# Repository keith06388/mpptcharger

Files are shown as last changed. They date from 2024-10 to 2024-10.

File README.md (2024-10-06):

# Backpacking MPPT Solar Charger
Solar charger designed to charge lithium ion cells directly, bypassing USB charging circuit.  


## Features

Advantages of this design:
* Very high efficiecy buck converter
* Psuedo MPPT tracking using BQ24650 chip
* Intergrated power meter and battery charge status
* Passthrough charging to charge device and battery simultaneously
* Integrated battery attachment for simple attachment to pack while hiking
* Adjustable to different panel voltages
* Avoid 2 stage voltage drop to cells for higher total efficiency (solar -> battery vs solar -> USB -> battery)
* Magnetic battery contacts designed to avoid reverse polarity connection
* Compatability with both Nitecore NL2150RX and Vapcell P2150A

## PCB
* Designed with easyeda software
* PCBA assembled by JLCPCB
* Primary components:
*   BQ24650 - mppt solar battery charging chip
*   ATTINY1616 - arduino compatable microcontroller
*   INA181A2 - current sense amplifier for power calculation

## 3D Printed Parts
* Housing (printed with ASA)
* Positve and negative battery contacts (printed with PETG)
*   Printing of the positive contact was paused to allow installation of the magnet into the housing before lip printed

## Purchased Parts
* Magents from K&J (D42AH and D62SH)
*   High temperature magnets to allow soldering without demagnetization
* Sn42Bi58 solder for attaching wire to magnets at low temperature
* 20AWG silicone flexible wire (red and black)
* 0.49" SSD1306 OLED
* 28.2mmx33mmx2.4mm 50D silicone o-ring
* 1.5mm nano tape (adds friction to prevent cell slipping)
* Short piece of flat wire (used for programming after assembly)
* Lixada solar panel

## Assembly
Testing of the performance was completed by modifying a Lixada solar panel purchased from Amazon

Installation steps:
* Carefully remove solar to USB module from panel using a razor blade to cut adhesive under module and a soldering iron to desolder leads from panel
* Scrape any remaining adhesive off and clean with alcohol
* Solder new assembled pcb with housing and leads to panel
* Use epoxy to glue housing to panel









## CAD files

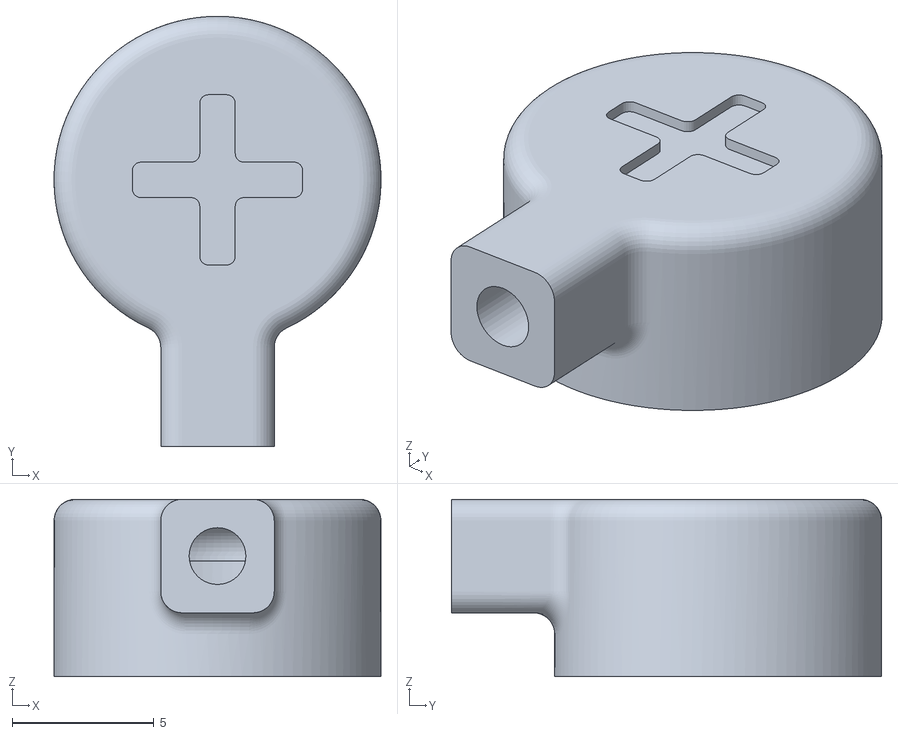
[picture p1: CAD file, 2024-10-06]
3D Printed Parts/Plus.stl
11.5 x 15.2 x 6.25

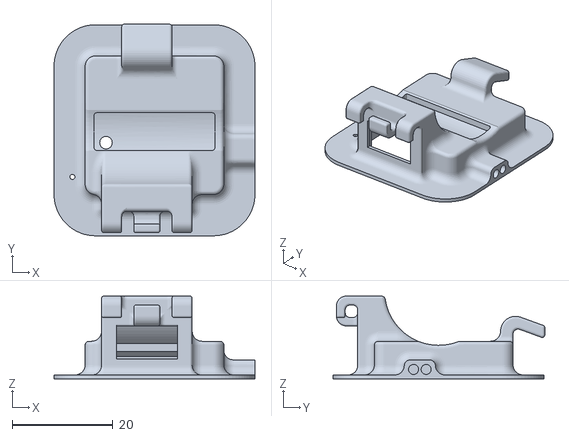
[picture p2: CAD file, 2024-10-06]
3D Printed Parts/Cover.stl
40.0 x 42.1 x 16.5

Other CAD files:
3D Printed Parts/Minus.3mf

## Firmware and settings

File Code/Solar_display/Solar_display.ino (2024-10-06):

#include <Tiny4kOLED.h>
#include "spleen.h"
#include "batt.h"

uint8_t currentCharacter;
uint8_t i = 0;
uint8_t lvl = 0;
uint8_t bar = 0;
uint8_t n = 0;

void setup() {
  oled.begin(64, 32, sizeof(tiny4koled_init_64x32), tiny4koled_init_64x32);
  oled.on();
  oled.switchRenderFrame();
  analogReference(INTERNAL2V5); // set reference to the desired voltage, and set that as the ADC reference.
}

void loop() {
  for (n = 0; n <4; n++){
    delay(250);
    float v = analogReadEnh(A7,13)/1654.62;
    float a = analogReadEnh(A6,13)/2129.92*0.92;
    if (v<3.60) lvl = 1;
    else if (v<3.79) lvl = 2;
    else if (v<3.97) lvl = 3;
    else if (v<4.10) lvl = 4;
    else lvl = 5;
    if (a>0.01) bar = lvl - i;
    else if (a<0.01 && v<3.3) bar = 0;
    else bar = lvl;
    oled.clear(); //all black
    oled.setFont(FONTspleen);
    oled.setCursor(0,0); 
    oled.print(v*a,2);
    oled.setCursor(36,0); 
    oled.print("/");
    oled.setCursor(48,0);
    oled.setFont(FONTbatt);
    oled.print(bar);
    oled.setFont(FONT6X8);
    oled.setCursor(14,2);
    oled.print(v,2);
    oled.print("V");
    oled.setCursor(14,3);
    oled.print(a,2);
    oled.print("A");
    oled.switchFrame();
  }
  n = 0;
  if (i==0) i=1;
  else i=0;
}
